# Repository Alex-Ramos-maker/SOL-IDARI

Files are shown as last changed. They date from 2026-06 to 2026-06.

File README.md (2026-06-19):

# SOL-IDARI
Kit de Cuina Solar de proximitat - Manual d'instruccions

La cuina solar és un dispositiu que utilitza exclusivament l'energia del sol per cuinar els aliments, sense necessitat de gas, electricitat ni llenya. Aquesta tecnologia és una aliada perfecta per a les àrees rurals i les comunitats petites, ja que fomenta l'autosuficiència energètica, redueix els costos vius i minimitza l'impacte ambiental en l'entorn local.
A més, encaixa idealment amb la filosofia de la cultura maker i la fabricació digital. Gràcies al disseny obert, qualsevol taller comunitari o FabLab pot descarregar els fitxers, imprimir les peces en 3D i muntar una cuina a mida adaptada a les necessitats del seu territori. És una eina de canvi que neix del treball col·laboratiu per crear comunitats més sostenibles i resilients.
Alguns dels seus components es poden comprar i d'altres s'han d'imprimir en impressora 3D. També n'hi ha que es poden reutilitzar d'algun aparell en desús.

Llicència Creative Commons: CC BY-NC-SA (Reconeixement - NoComercial - CompartirIgual).


https://creativecommons.org/licenses/by-nc-sa/4.0/

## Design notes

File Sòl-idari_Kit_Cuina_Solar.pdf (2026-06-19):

# SÒL-IDARI

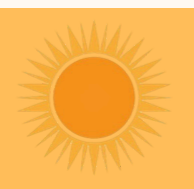
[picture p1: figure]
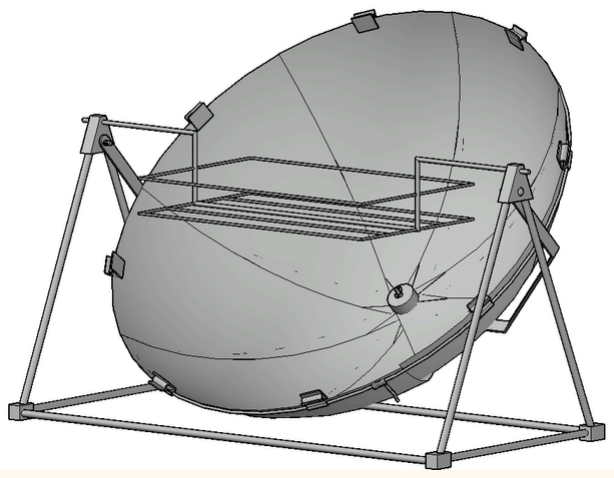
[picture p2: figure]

Disseny col·laboratiu

Juny de 2026 | Àlex Ramos Fernández

## Kit de Cuina Solar de proximitat

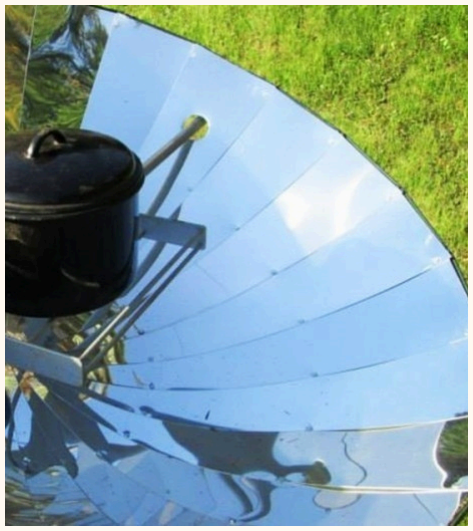
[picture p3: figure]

La cuina solar és un dispositiu que utilitza exclusivament l'

energia del sol per cuinar els aliments, sense necessitat de gas, electricitat ni llenya. Aquesta tecnologia és una aliada perfecta per a les àrees rurals i les comunitats petites, ja que fomenta l'

autosuficiència
energètica, redueix els costos vius i minimitza l'impacte ambiental en l'

entorn local.

A més, encaixa idealment amb la filosofia de la cultura maker i la fabricació digital. Gràcies al disseny obert, qualsevol taller comunitari o FabLab pot descarregar els fitxers, imprimir les peces en 3D i muntar una cuina a mida adaptada a les necessitats del seu territori. És una eina de canvi que neix del treball col·laboratiu per crear comunitats més sostenibles i resilients.

## CUINA SOLAR

## MATERIALS NECESSARIS

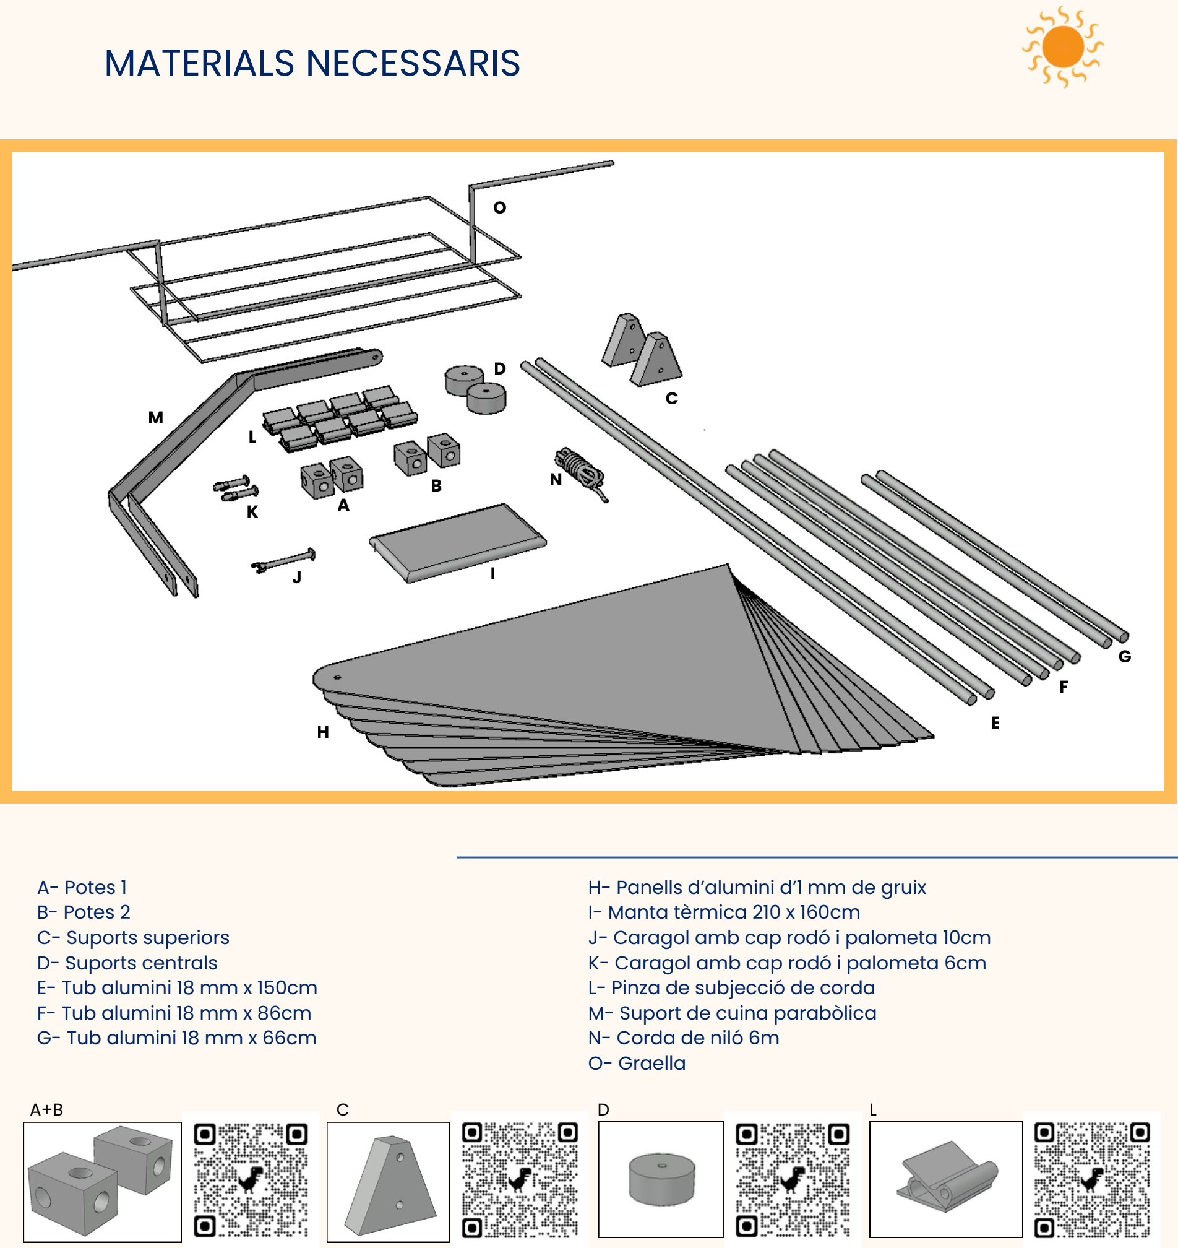
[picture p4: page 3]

A- Potes 1
B- Potes 2
C- Suports superiors
D- Suports centrals
E- Tub alumini 18 mm x 150cm F- Tub alumini 18 mm x 86cm G- Tub alumini 18 mm x 66cm

H- Panells d’alumini d’1 mm de gruix
I- Manta tèrmica 210 x 160cm
J- Caragol amb cap rodó i palometa 10cm K- Caragol amb cap rodó i palometa 6cm L- Pinza de subjecció de corda
M- Suport de cuina parabòlica
N- Corda de niló 6m
O- Graella

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
A+B | C | D | L

B N

C

D

## ESTRUCTURA BÀSICA

1

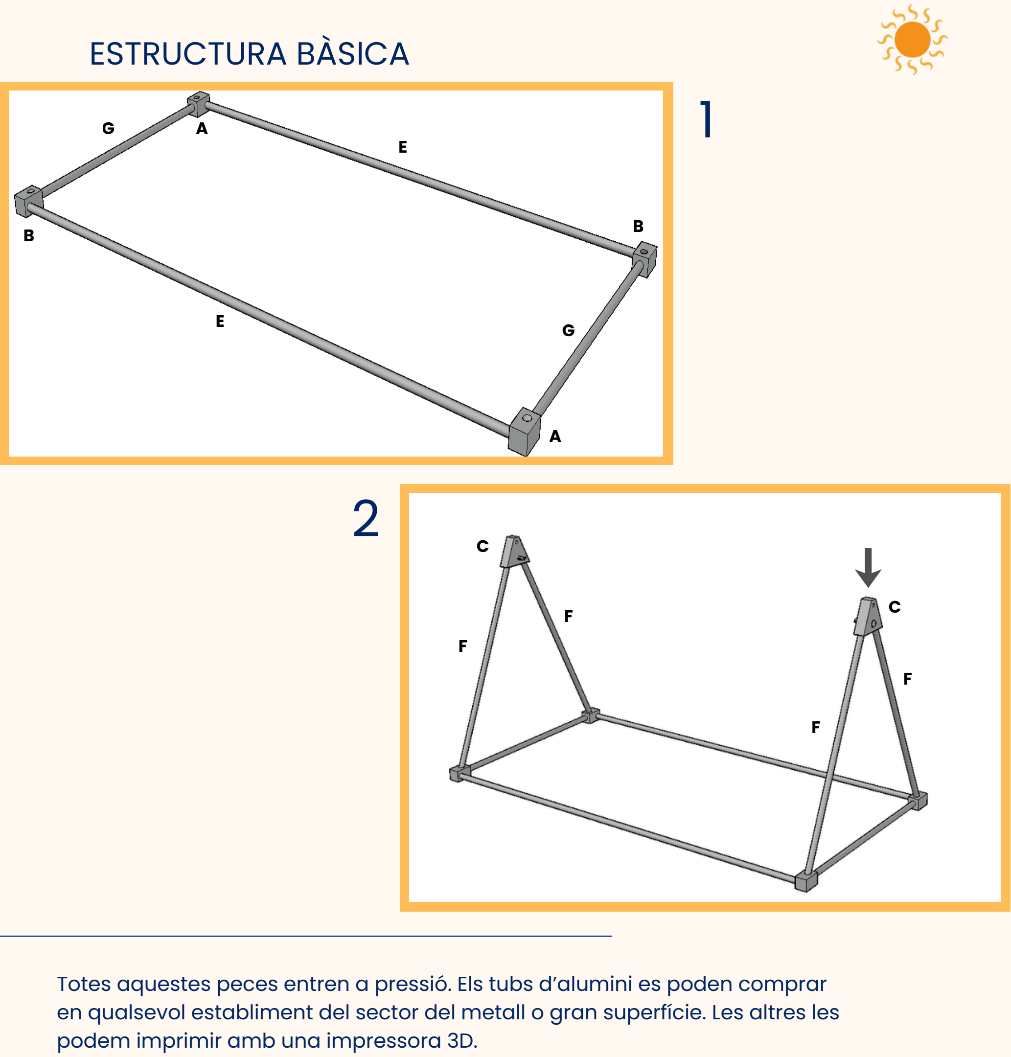
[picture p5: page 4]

Totes aquestes peces entren a pressió. Els tubs d’alumini es poden comprar en qualsevol establiment del sector del metall o gran superfície. Les altres les podem imprimir amb una impressora 3D.

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
## ESTRUCTURA BÀSICA

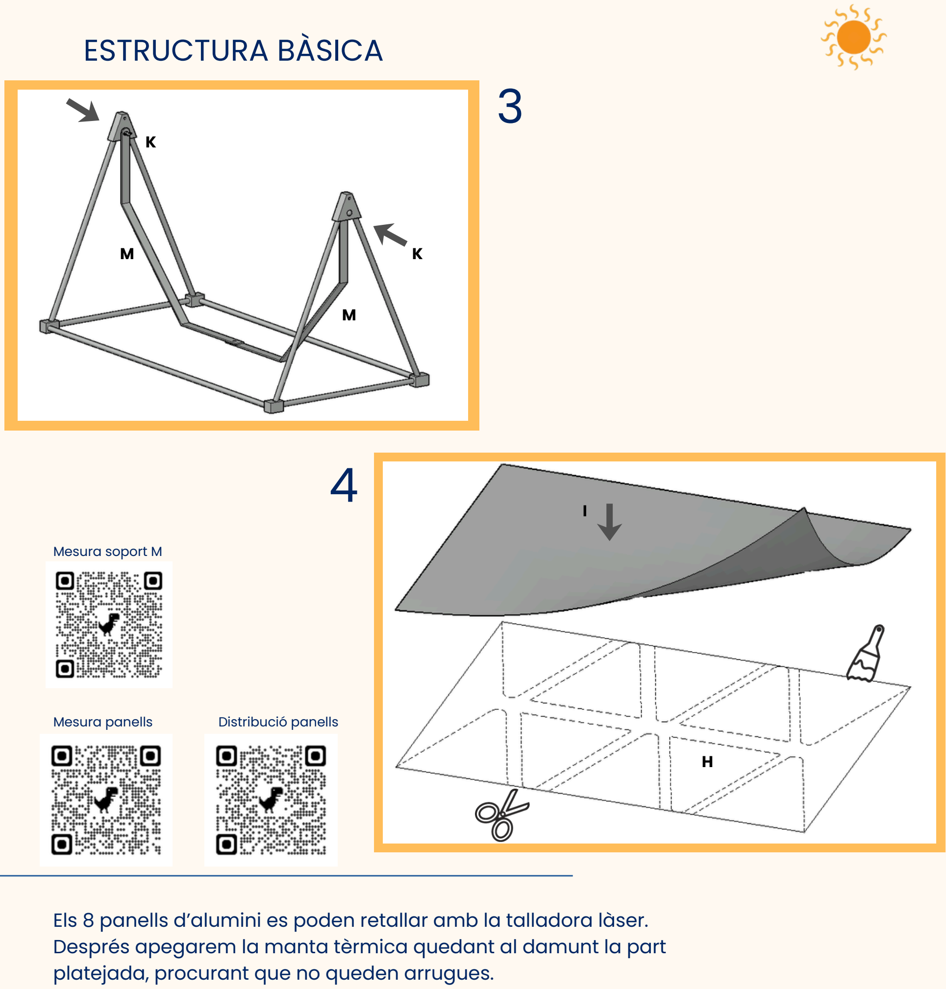
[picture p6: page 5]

M

M

K

K

Els 8 panells d’alumini es poden retallar amb la talladora làser. Després apegarem la manta tèrmica quedant al damunt la part platejada, procurant que no queden arrugues.

Mesura panells

Mesura soport M

Distribució panells

4 | I

H

5

## ESTRUCTURA BÀSICA

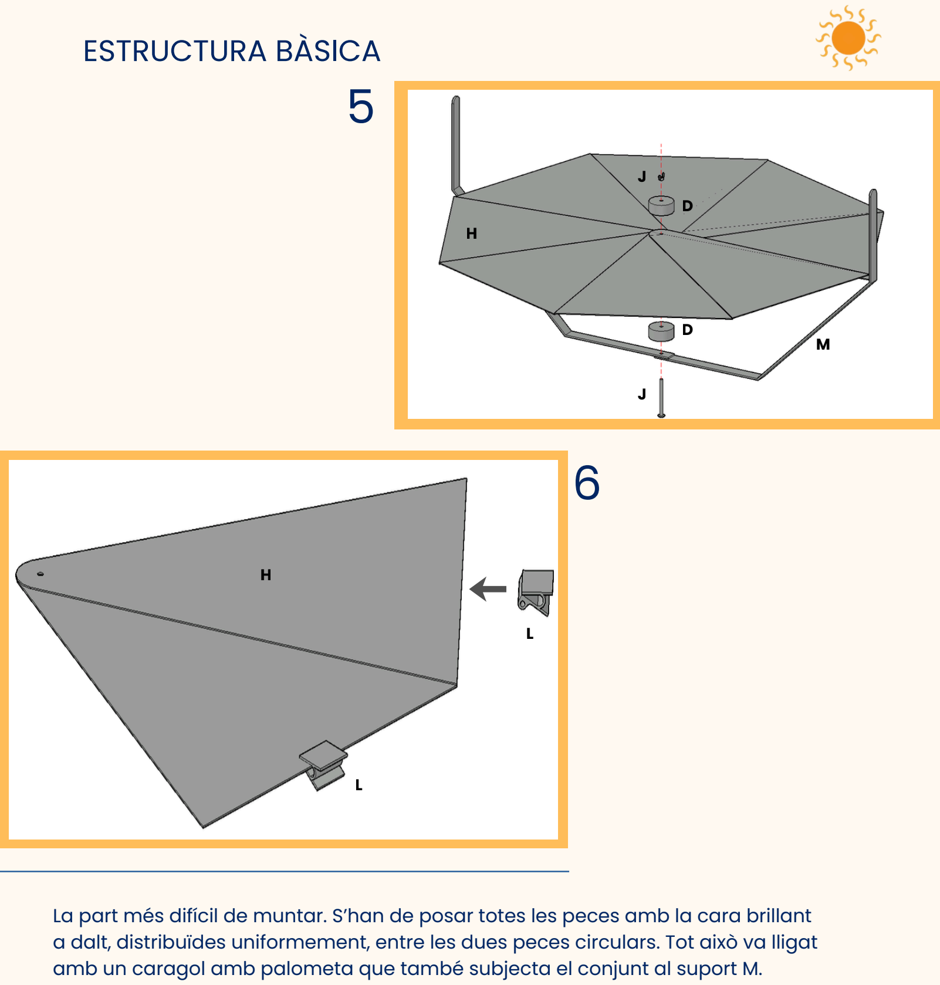
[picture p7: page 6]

M

H

J

J

D

D

La part més difícil de muntar. S’han de posar totes les peces amb la cara brillant a dalt, distribuïdes uniformement, entre les dues peces circulars. Tot això va lligat amb un caragol amb palometa que també subjecta el conjunt al suport M.

6

L

L

H

7

## ESTRUCTURA BÀSICA

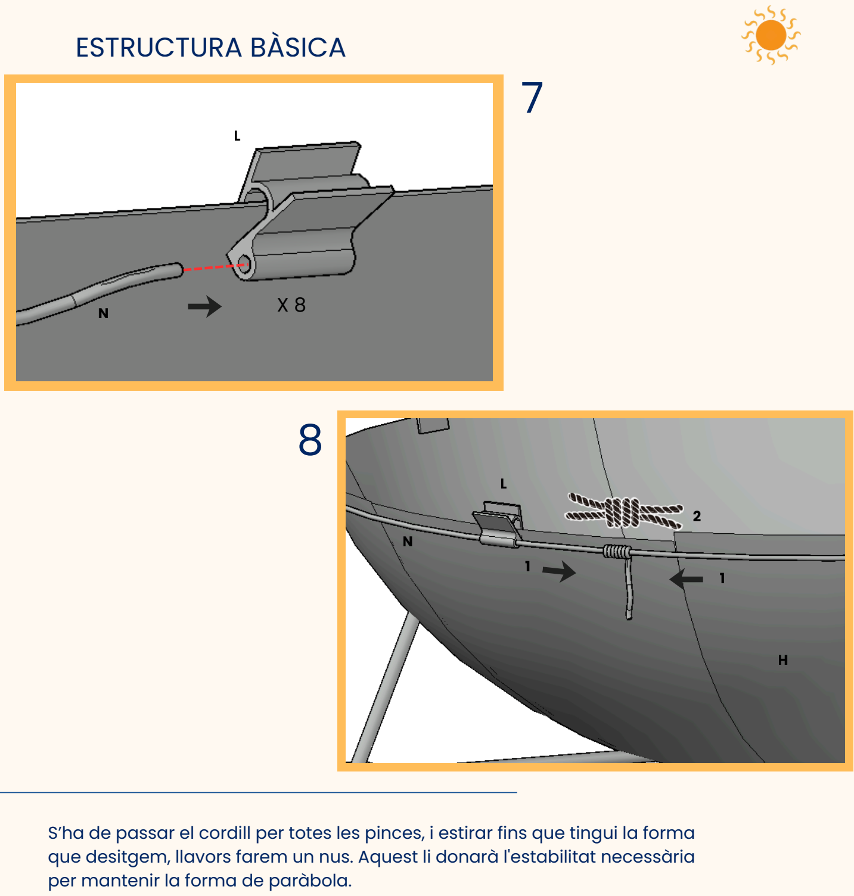
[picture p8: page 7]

L

X 8

S’ha de passar el cordill per totes les pinces, i estirar fins que tingui la forma que desitgem, llavors farem un nus. Aquest li donarà l'

estabilitat necessària
per mantenir la forma de paràbola.

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
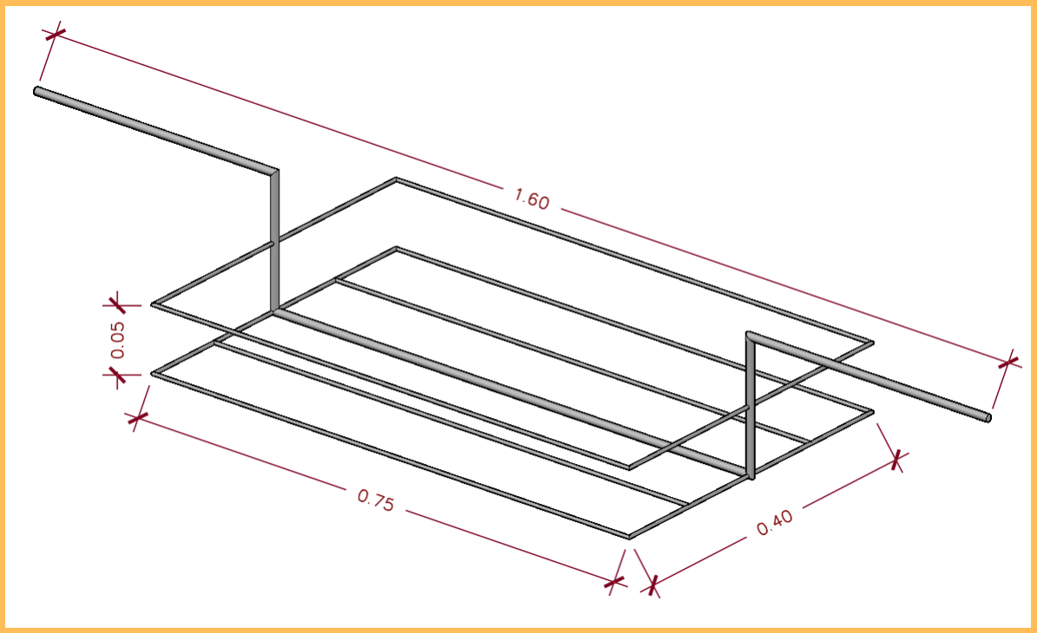
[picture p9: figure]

Graella receptora de l’aparell per cuinar. Confeccionada de manera manual amb material metàl·lic. Potser soldat o ensamblat amb brides metàl·liques. Les seves mesures poden variar segons les necessitats i la mida de la cuina que construïm.

El mateix passa amb les barres de suport a la paràbola, pot ser una barra metàl·lica doblada, reaprofitada de qualsevol estructura que no usem. Les mides també estan condicionades a la mida general de la cuina que construim.

## OBJETIVO DE LA TAREA

Por qué es importante

## RESULTAT FINAL

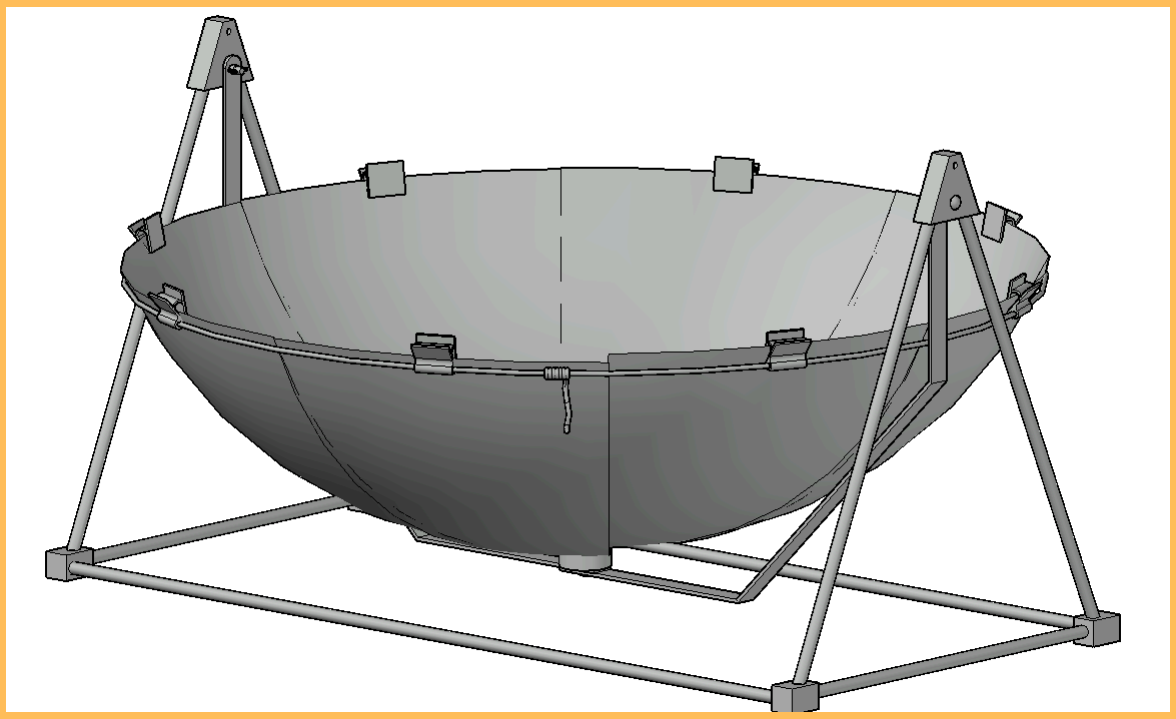
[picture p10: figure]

## MECANISME DE GIR

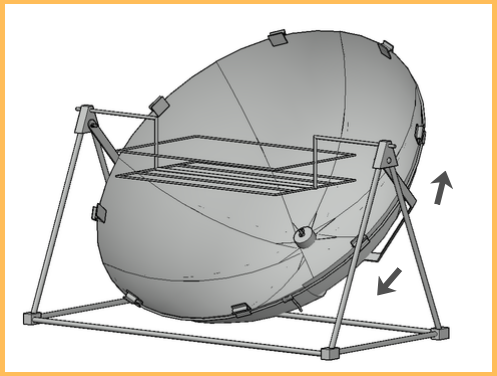
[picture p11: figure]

## SEGURETAT

El mateix suport de la paràbola, les barres corbes M, són el mecanisme de gir, que podem moure per adaptar el focus a mida que es mou el sol,
mitjançant les dos palometes que el subjecten, per tal de mantenir el focus baix la
graella.

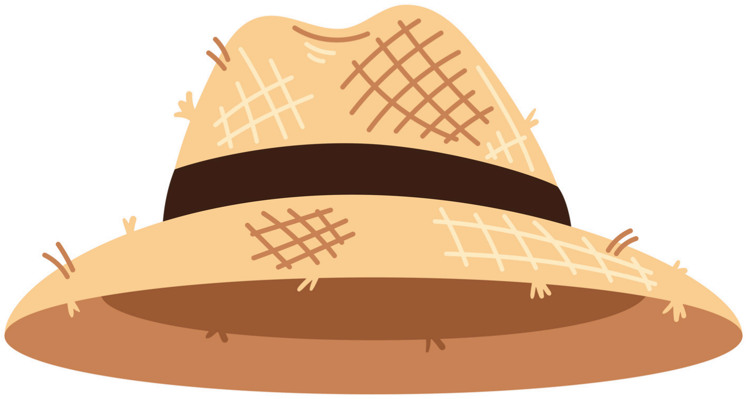
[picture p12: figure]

Feu servir sempre protecció contra la radiació solar. Encara que no ho sembli, els utensilis que utilitzem estan molt calents i ens podem cremar. Guants, barret, ulleres i crema solar són imprescindibles.

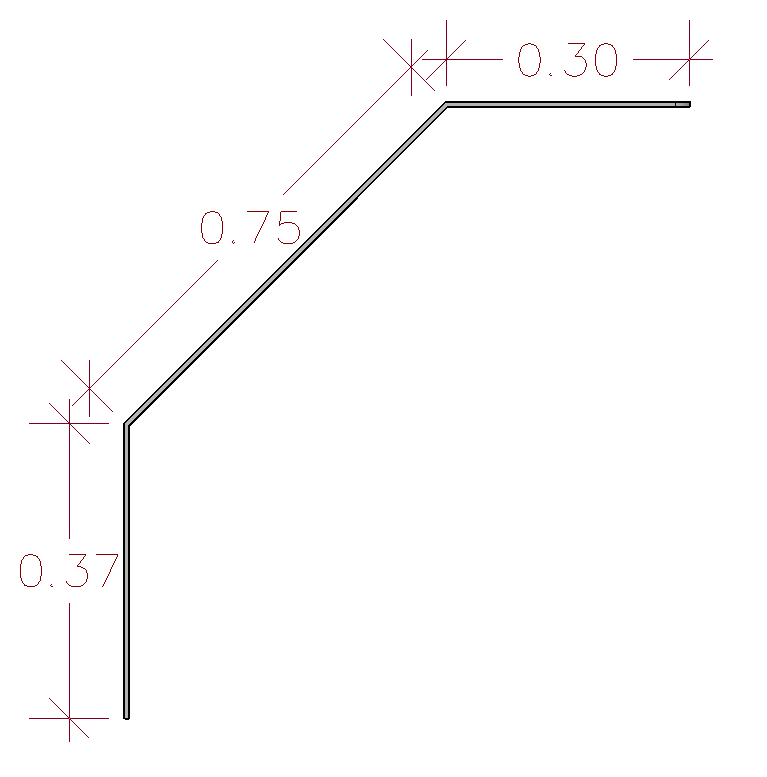
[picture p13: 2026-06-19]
Suport de paràbola.png

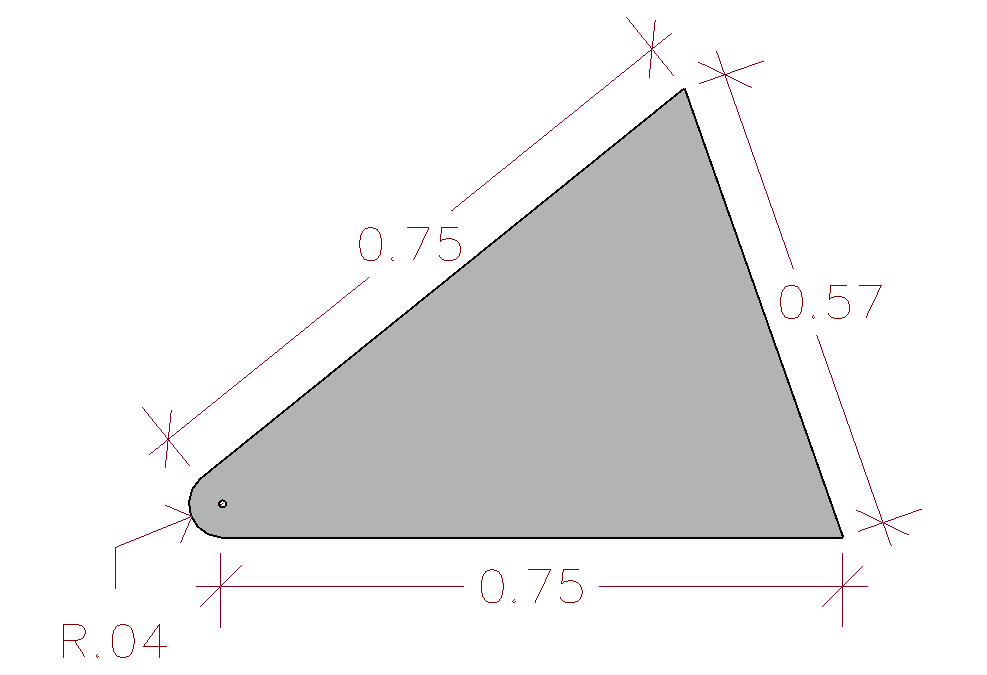
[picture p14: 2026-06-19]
Mesures panell.png

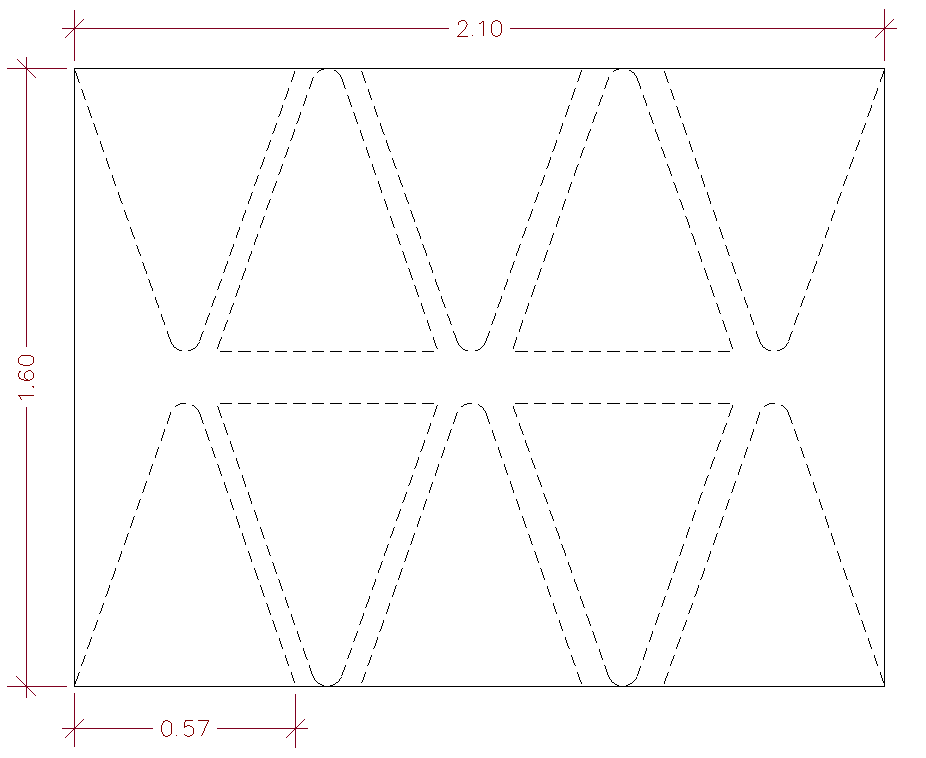
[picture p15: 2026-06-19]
Distibució peces.png

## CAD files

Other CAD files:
Potes1 i 2.gcode.3mf
Suports_centrals.gcode.3mf
Suports superiors.gcode.3mf
